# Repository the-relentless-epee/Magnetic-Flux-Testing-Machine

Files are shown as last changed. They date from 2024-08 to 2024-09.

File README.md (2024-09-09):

# Magnetic-Flux-Testing-Machine
A machine to collect data on how magnetic flux changes over distance. The end goal is to test how the air gap in an electric motor affects its performance. The machine involves spinning a disc of neodynium magnets next to a coil. The distance between the magnet disc and the coil is changed using a stepper motor, and the voltage across the coil is measured.

**Overall Assembly:**



**PCB:**





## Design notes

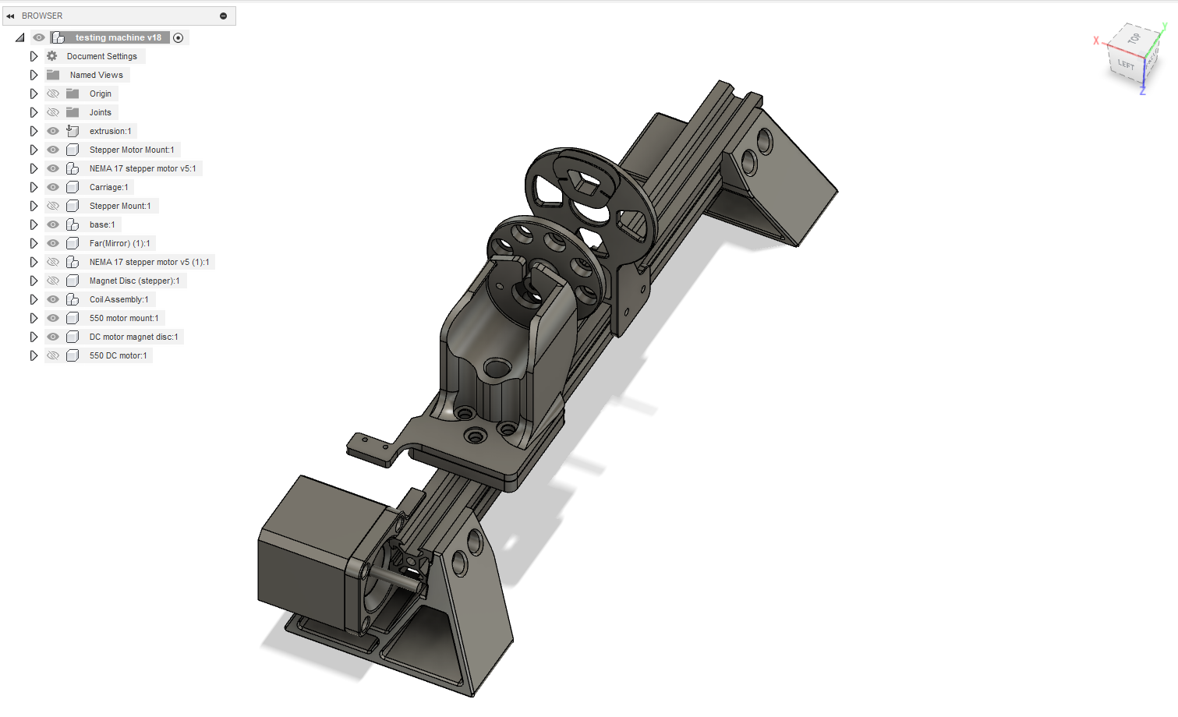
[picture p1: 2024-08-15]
CAD/Screenshot 2024-08-14 223211.png

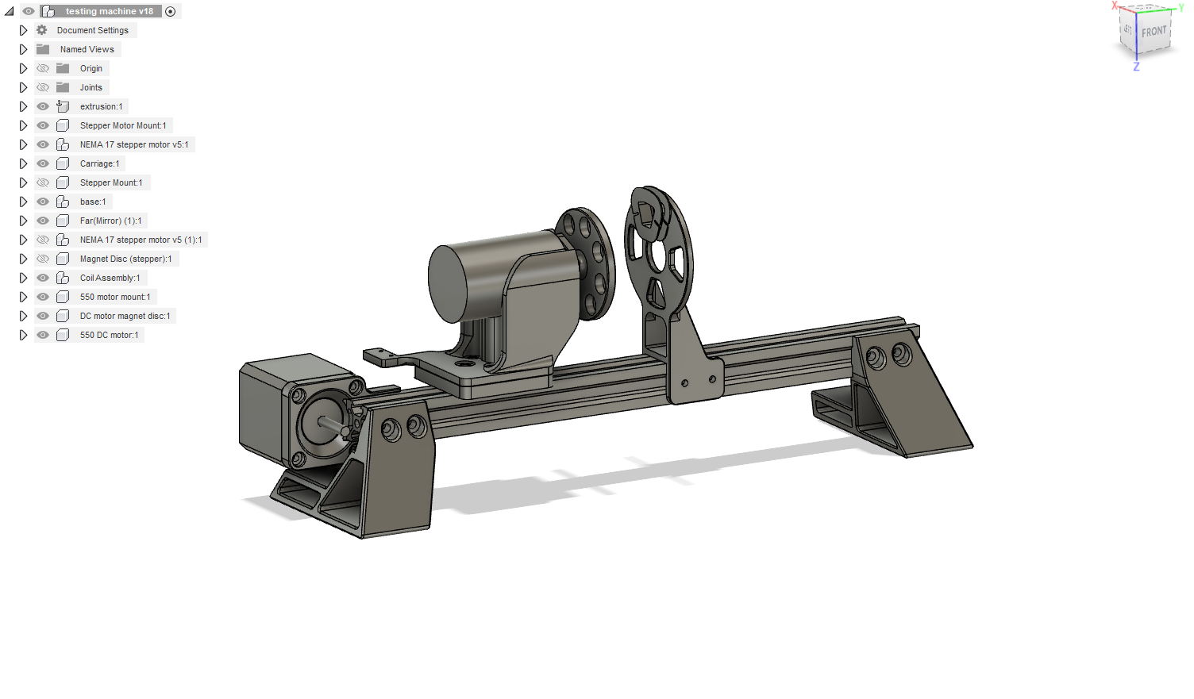
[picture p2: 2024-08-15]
CAD/Screenshot 2024-08-14 223127.png

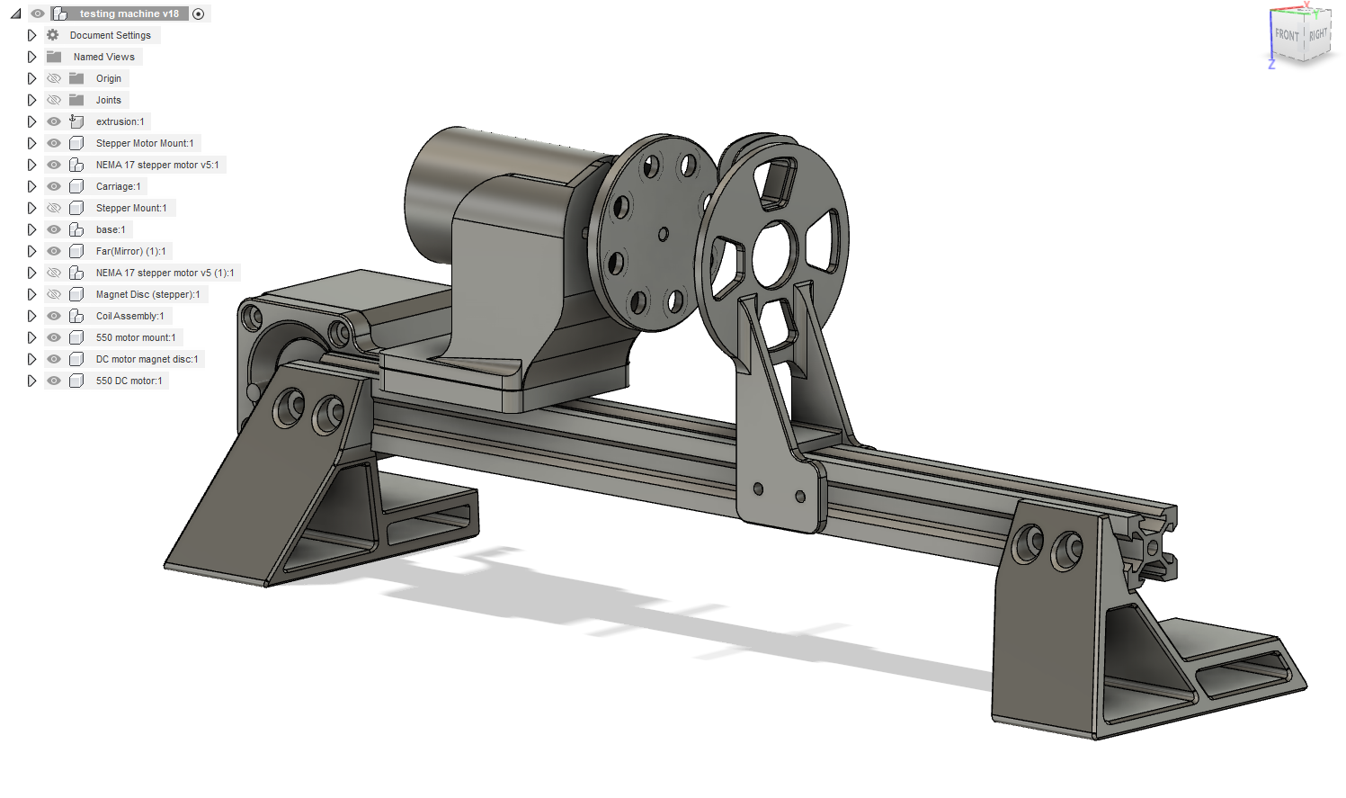
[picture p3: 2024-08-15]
CAD/Screenshot 2024-08-14 223146.png

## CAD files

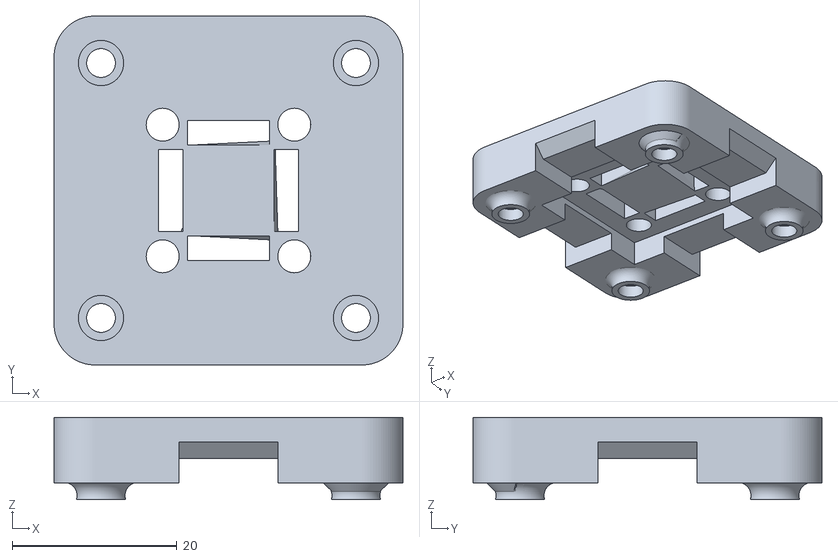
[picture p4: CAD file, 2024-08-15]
CAD/AS5600 stepper mount remix v1.stl
42.4 x 42.4 x 10.0

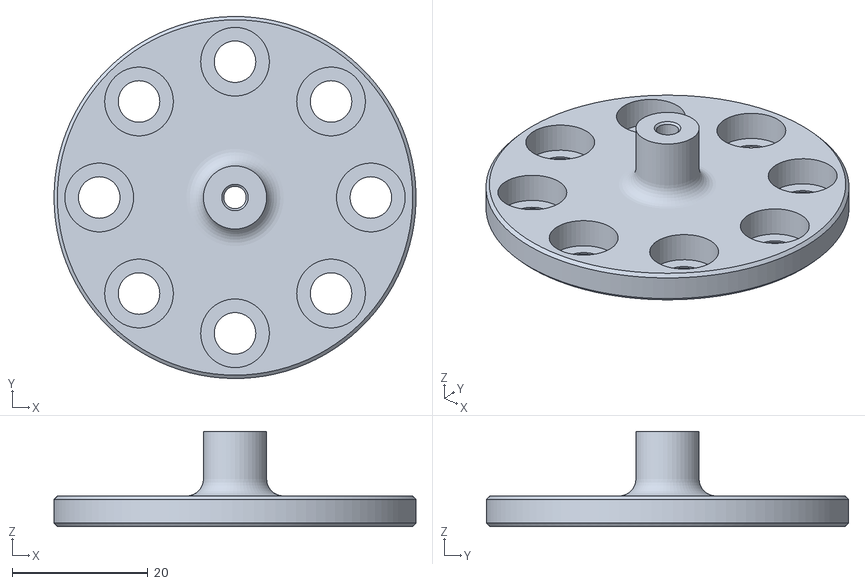
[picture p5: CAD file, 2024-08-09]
CAD/DC motor magnet disc V1.stl
53.3 x 53.3 x 14.0

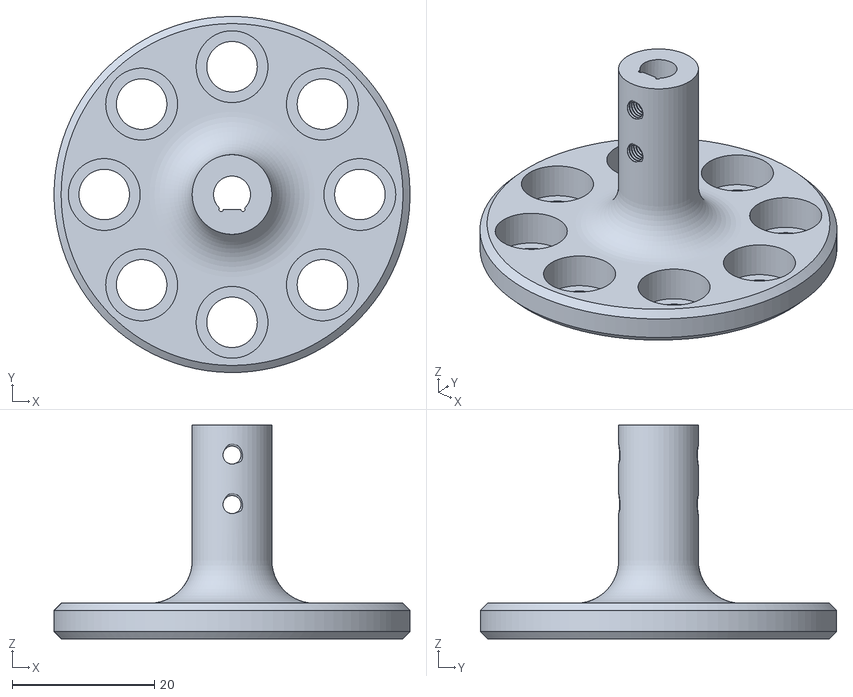
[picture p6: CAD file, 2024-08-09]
CAD/Magnet Disc V1 10x4.stl
50.0 x 50.0 x 30.0

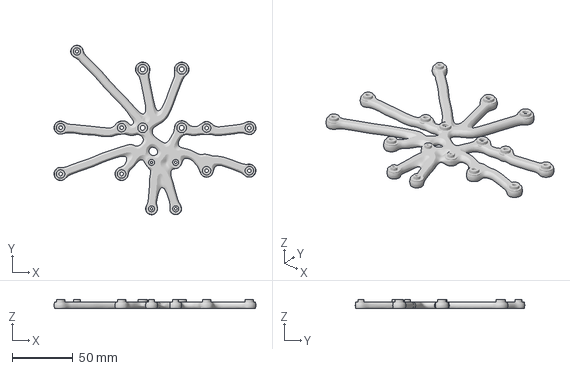
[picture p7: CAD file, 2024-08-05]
CAD/Base V1.2.3mf
165.6 x 139.0 x 7.30 mm

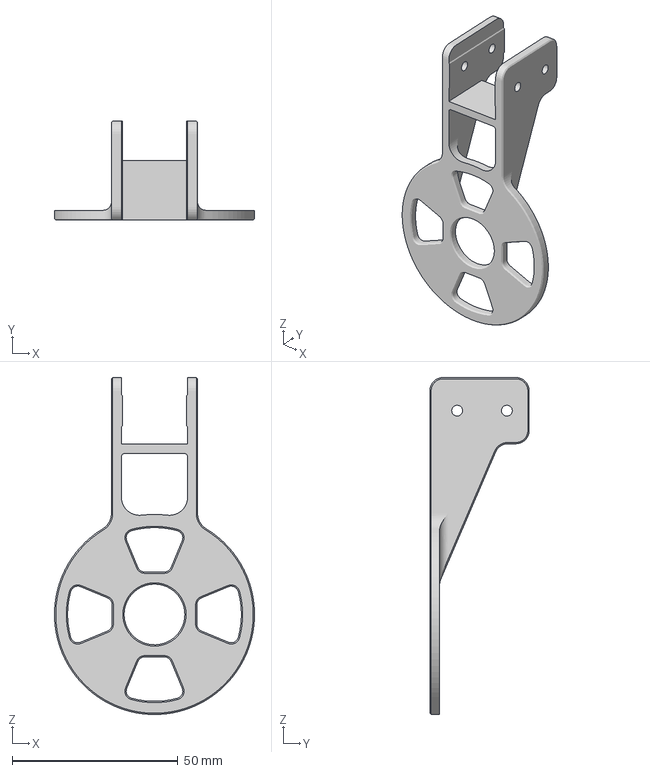
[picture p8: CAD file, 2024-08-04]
CAD/CoilBase V1.3.3mf
60.4 x 30.0 x 101.7 mm

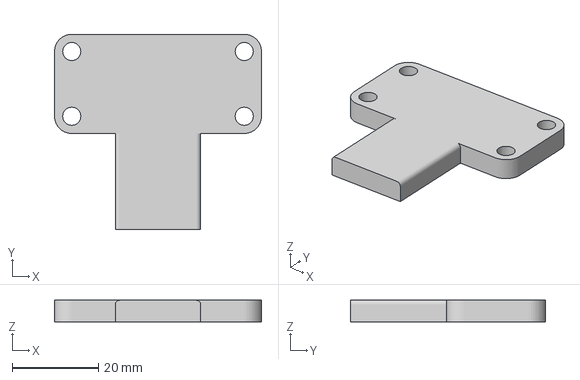
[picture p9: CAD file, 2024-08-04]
CAD/CoilBoard base adapter.3mf
48.0 x 45.3 x 5.00 mm

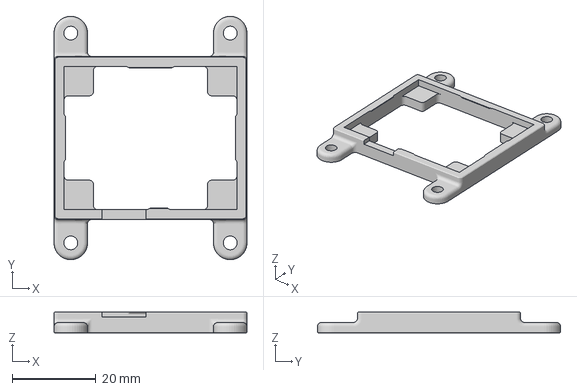
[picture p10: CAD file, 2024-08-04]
CAD/Power Board case V1.3mf
46.0 x 58.0 x 5.00 mm

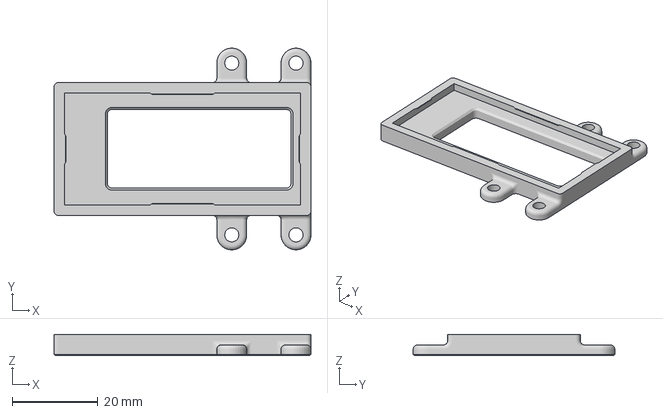
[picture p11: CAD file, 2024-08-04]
CAD/Coil board case V1.3mf
60.0 x 47.1 x 5.00 mm

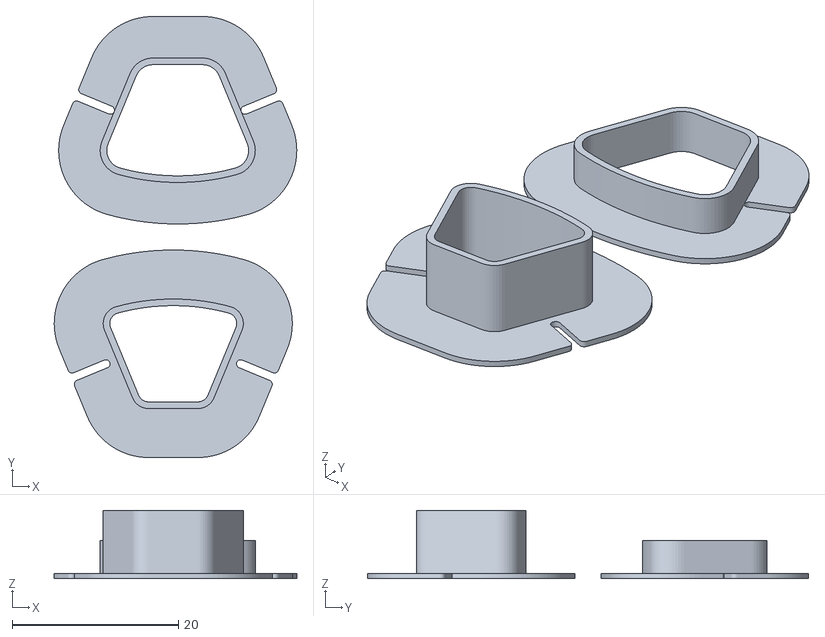
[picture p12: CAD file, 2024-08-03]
CAD/Coil V2.2.stl
29.2 x 53.1 x 8.20

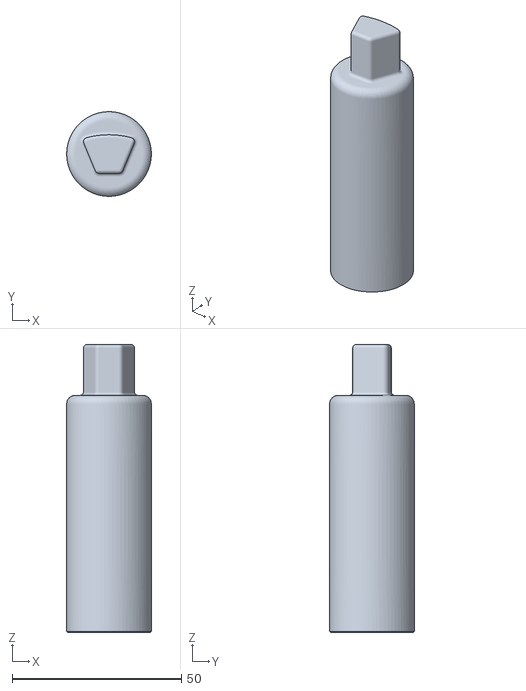
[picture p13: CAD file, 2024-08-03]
CAD/Coil winding tool.stl
25.0 x 25.0 x 85.0

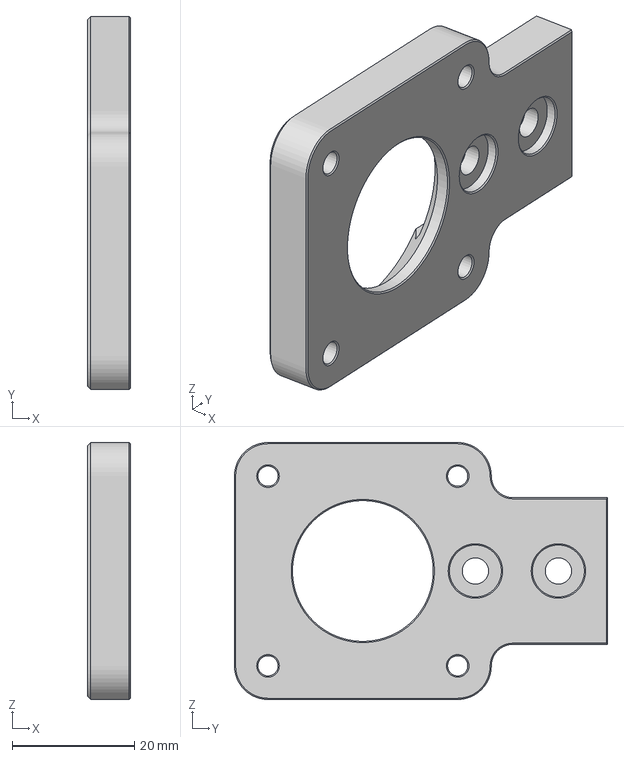
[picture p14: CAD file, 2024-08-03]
CAD/Stepper Motor Mount V1.3mf
7.00 x 61.0 x 42.0 mm

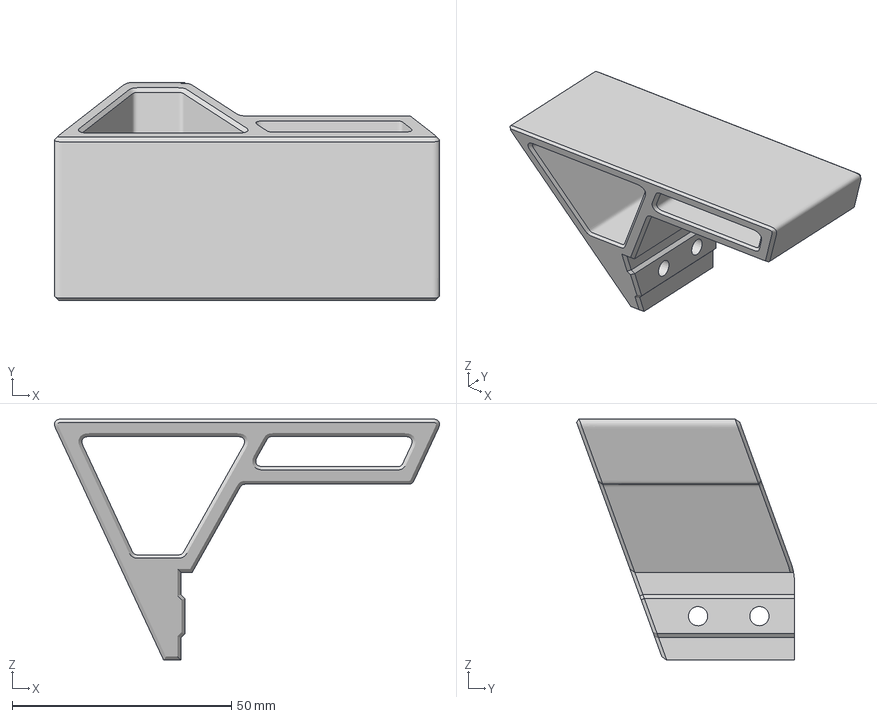
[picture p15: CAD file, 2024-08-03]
CAD/close leg V1.3mf
87.9 x 49.7 x 55.0 mm

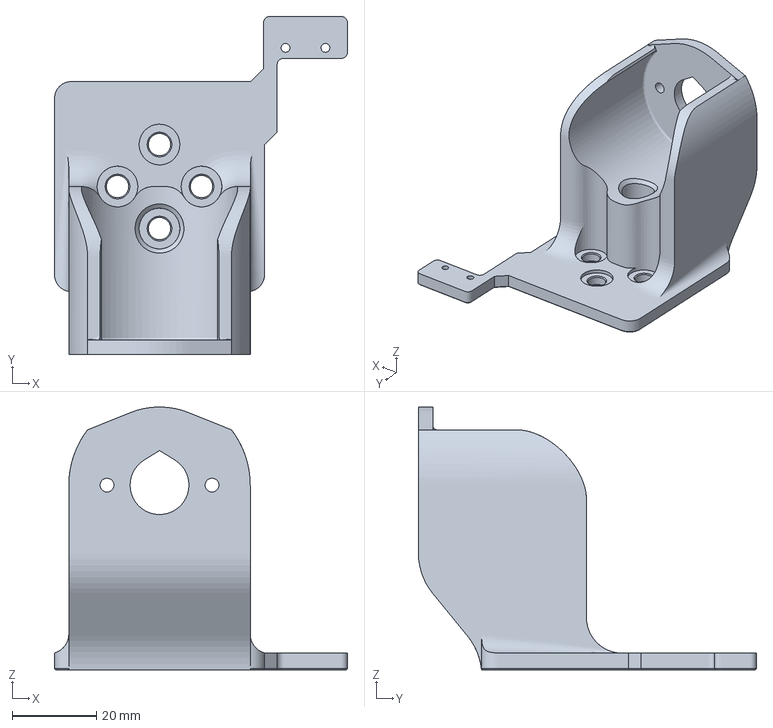
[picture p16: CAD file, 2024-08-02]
CAD/550 motor mount V1.3mf
69.8 x 80.5 x 62.6 mm

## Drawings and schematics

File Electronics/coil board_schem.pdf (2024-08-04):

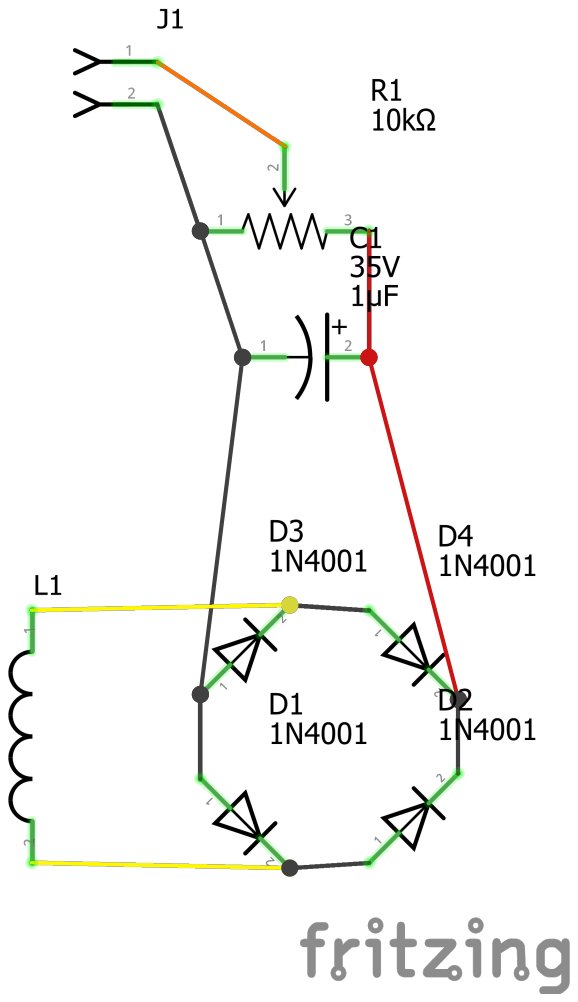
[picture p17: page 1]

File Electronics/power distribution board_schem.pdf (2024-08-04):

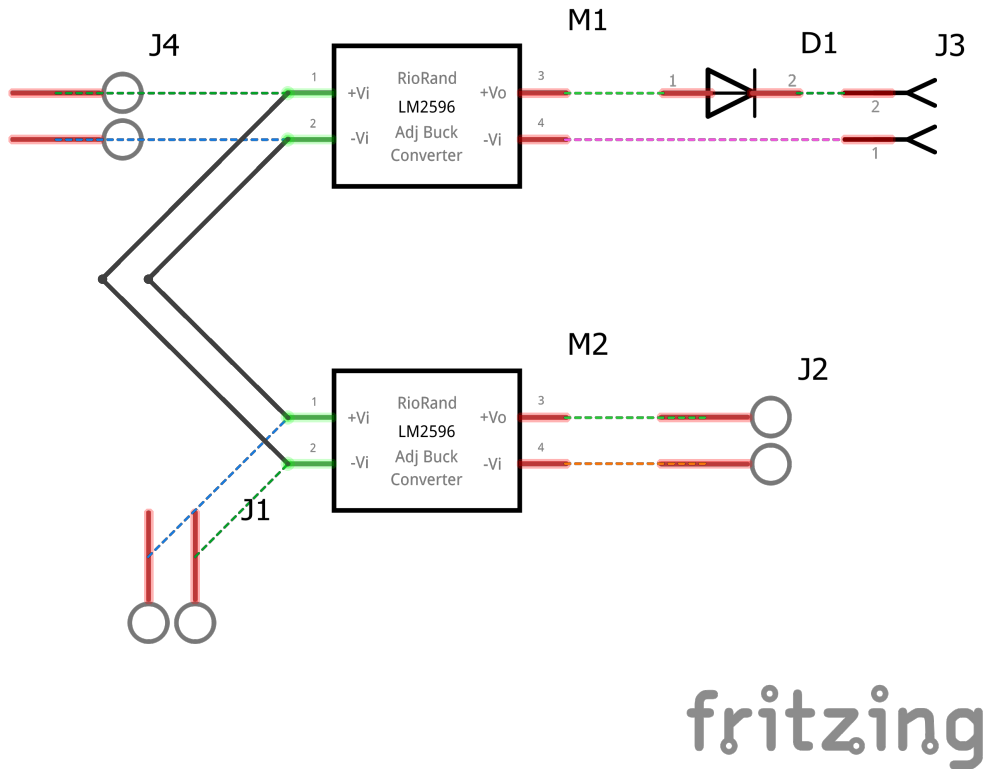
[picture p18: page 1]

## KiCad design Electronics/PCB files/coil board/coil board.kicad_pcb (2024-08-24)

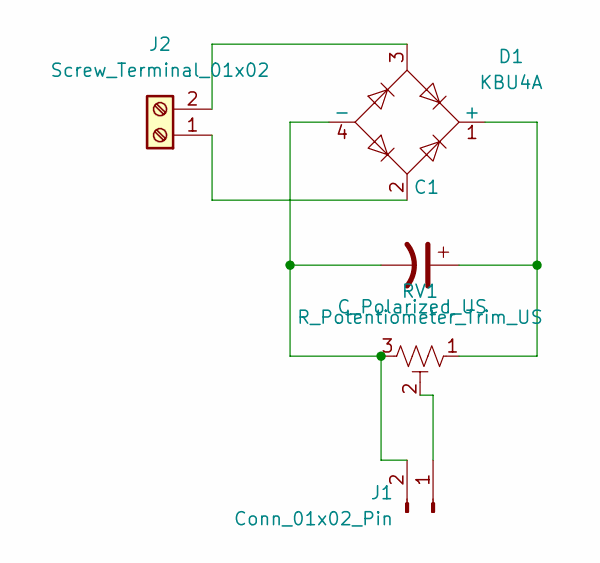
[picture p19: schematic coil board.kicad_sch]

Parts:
C1: C_Polarized_US; CP_Radial_D4.0mm_P2.00mm
D1: KBU4A; Diode_Bridge_Vishay_KBU
J1: Conn_01x02_Pin; PinHeader_1x02_P2.54mm_Vertical
J2: Screw_Terminal_01x02; TerminalBlock_RND_205-00232_1x02_P5.08mm_Horizontal
RV1: R_Potentiometer_Trim_US; Potentiometer_Vishay_T93YA_Vertical

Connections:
unnamed: C1.1, D1.1 (+), RV1.1
unnamed: C1.2, D1.4 (-), J1.2, RV1.3
unnamed: J1.1, RV1.2
unnamed: D1.2, J2.1
unnamed: D1.3, J2.2

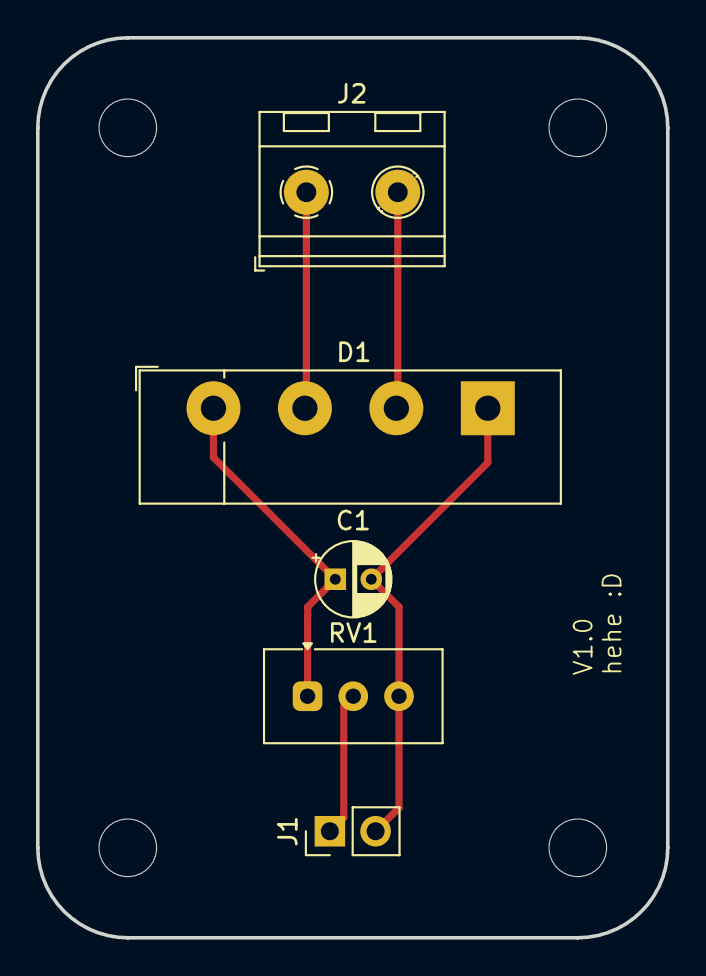
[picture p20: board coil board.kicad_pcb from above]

Board: 2 copper layers, 35.0 x 50.0 mm, 5 parts (0 on the bottom side), 5 nets.

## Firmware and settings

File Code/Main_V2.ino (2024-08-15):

//==========================libraries
#include <Arduino.h>
#include "BasicStepperDriver.h"

#include <SPI.h>
#include <SD.h>
//==========================pin definitions

# define M1 10//dc driver
# define M2 11//dc driver
# define EN 13
# define STEP 16//stepper
# define DIR 15//stepper
# define ADC 26
# define endStop 1
const int _MISO = 4;  // AKA SPI RX
const int _MOSI = 3;  // AKA SPI TX
const int _CS = 5;
const int _SCK = 2;

//==========================variables

//stepper
#define MS 4
#define MOTOR_STEPS 200
#define RPM 60
#define STEPS_PER_MM 5

BasicStepperDriver stepper(MOTOR_STEPS, DIR, STEP, EN);


//logging
#define samplesCount 10000 //samples taken per measurement cycle
#define sampleTime 5000 //sampling time in milliseconds
#define samplingInterval samplesCount/sampleTime*1000 //interval between samples in us
#define sampleDelay 1000 //delay to let voltage settle before sampling


//movement
#define moveDistance 30 //total testing distance in mm
#define stepDistance 0.1 //distance of each step in mm

#define coilDistance 60 //distance from home to coil in mm
#define initialDistance 0.2 //distance to start from coil in mm

float currentPos = 0;  //actual distance from home, in mm
int cycleCount = moveDistance/stepDistance; 
unsigned long prevMicros = 0;
unsigned long currentMicros = 0;


//==================================functions
//homing
void home(){
  Serial.println("homing");
  while (digitalRead(endStop)==1){
    stepper.move(-0.5*STEPS_PER_MM*MS); //course homing moves 0.5mm at a time
  }
  delay(100);
  stepper.move(5*STEPS_PER_MM*MS); //move back 5mm to reset the switch
  while(digitalRead(endStop)==1){ //fine homing moves one step at a time
    stepper.move(-1);
    delay(10);
  }
  Serial.println("homed");

  stepper.move(coilDistance*STEPS_PER_MM*MS);
  delay(100);
  stepper.move(-initialDistance*STEPS_PER_MM*MS);
  currentPos = coilDistance-initialDistance;
  Serial.println("homed and ready");
}
//DC motor 
void spinMotor(){
  digitalWrite(M1, 1);
  analogWrite(M2, 255); //simplified to go full speed all the time
}
void stopMotor(){
  digitalWrite(M1, 1);
  digitalWrite(M2, 1);
}
//data logging
void logData(int distance){
  File dataFile = SD.open("datalog.txt", FILE_WRITE);
  for (int i = 0; i<(samplesCount+1); i++){
    currentMicros = micros();
    while (currentMicros-prevMicros<samplingInterval){
      int data = analogRead(ADC);
      if (dataFile) {
        dataFile.print(distance);
        dataFile.print(", ");
        dataFile.println(data);
        //dataFile.close(); s
        Serial.print(distance);
        Serial.print(", ");
        Serial.println(data);
      }
      // if the file isn't open, pop up an error:
      else {
        Serial.println("error opening datalog.txt");
        break;
      }
      prevMicros = currentMicros;
    }
  }
}

//====================================================
void setup(){
  //Serial
  Serial.begin(115200);

  //SD
  Serial.println("initializing SD card");
  bool sdInitialized = false;
  SPI.setRX(_MISO);
  SPI.setTX(_MOSI);
  SPI.setSCK(_SCK);
  sdInitialized = SD.begin(_CS);
  if (!sdInitialized) {
    Serial.println("initialization failed. Things to check:");
    Serial.println("* is a card inserted?");
    Serial.println("* is your wiring correct?");
    Serial.println("* did you change the chipSelect pin to match your shield or module?");
    return;
  } else {
    Serial.println("Wiring is correct and a card is present.");
  }
  File dataFile = SD.open("datalog.txt", FILE_WRITE);

  //pin definition
  pinMode(endStop, INPUT_PULLDOWN);
  pinMode(ADC, INPUT);

  //stepper
  stepper.begin(RPM, MS);
  stepper.setEnableActiveState(LOW);
  stepper.enable(); 

  //variables
  currentPos = 0;
  delay(1000);
}

void loop(){
  home();
  File dataFile = SD.open("dataLog.txt", FILE_WRITE|O_TRUNC);
  dataFile.println("start");
  spinMotor();
  delay(1500);  
  for (int i = initialDistance; i<=moveDistance; i += stepDistance){
    delay(sampleDelay);
    logData(i);
    delay(100);
    stepper.move(-(stepDistance*STEPS_PER_MM*MS));
  }
  delay(100);
  stopMotor();
  dataFile.println("finished");
  while(true){
    stepper.disable();
  }
}

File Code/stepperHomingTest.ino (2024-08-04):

/*
 * Simple demo, should work with any driver board
 *
 * Connect STEP, DIR as indicated
 *
 * Copyright (C)2015-2017 Laurentiu Badea
 *
 * This file may be redistributed under the terms of the MIT license.
 * A copy of this license has been included with this distribution in the file LICENSE.
 */
#include <Arduino.h>
#include "BasicStepperDriver.h"

// Motor steps per revolution. Most steppers are 200 steps or 1.8 degrees/step
#define MOTOR_STEPS 200
#define RPM 60

// Since microstepping is set externally, make sure this matches the selected mode
// If it doesn't, the motor will move at a different RPM than chosen
// 1=full step, 2=half step etc.
#define MICROSTEPS 2

// All the wires needed for full functionality
#define DIR 15
#define STEP 16
#define EN 13
#define switchPin 14
//Uncomment line to use enable/disable functionality
//#define SLEEP 13

// 2-wire basic config, microstepping is hardwired on the driver
BasicStepperDriver stepper(MOTOR_STEPS, DIR, STEP, EN);

//Uncomment line to use enable/disable functionality
//BasicStepperDriver stepper(MOTOR_STEPS, DIR, STEP, SLEEP);

//step/mm = 5

int currentPos;
int coilDistance = 300*MICROSTEPS;

void home() {
  while (digitalRead(switchPin)==1){
    stepper.move(-2);
    currentPos -= 2;
    Serial.println(currentPos);
    delay(1);
  }
  delay(100);
  stepper.move(MICROSTEPS*10);
  while(digitalRead(switchPin)==1){
    stepper.move(-1);
    currentPos -= 1;
    Serial.println(currentPos);
    delay(100);
  }
  currentPos = 0;
}

void setup() {
  Serial.begin(115200);
  pinMode(switchPin, INPUT_PULLDOWN);
  stepper.begin(RPM, MICROSTEPS);
  stepper.setEnableActiveState(LOW);
  
  stepper.enable();
  stepper.move(MICROSTEPS*2);
  currentPos = 0;
    // if using enable/disable on ENABLE pin (active LOW) instead of SLEEP uncomment next line
  
}

void loop(){
  home();
  stepper.move(coilDistance);
  currentPos = coilDistance;
  Serial.println(currentPos);
  while(true){
    stepper.disable();
  }
}

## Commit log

2024-08-02 550 motor mount upload
    V1 of the "spindle" motor mount. Uses 550 DC motor, mounts onto a commonly available V-roller carriage with M5 screws. included a spot to mount a microswitch for homing.
    [550 motor mount V1.3mf]
2024-08-02 added 8x magnet rotor disc for 550 DC motor
    [DC motor magnet disc V1.2.3mf]
2024-08-03 added legs (mirror of each other)
    this is a "base" that screws onto the v-slot extrusion using M4 T-nuts. Made so that the center of gravity of the whole machine is well supported.
    [close leg V1.3mf]
2024-08-03 added stepper mount for linear movement
    uses gt2 pulley, designed to be as close to the extrusion as possible.
    [Stepper Motor Mount V1.3mf]
2024-08-03 added coil and tool for winding the wires
    uses 0.2mm enameled copper wire. ~200 turns each, 4 in total. The two halves fit over each other and should be glued.
    [Coil V2.2.stl, Coil winding tool.stl]
2024-08-03 added body to mount 4 coils to extrusion
    uses m3 bolts and t-nuts to mount to extrusion. Coils are glued to their alignment slots
    [coil body V1.3mf]
2024-08-04 initial function tests for hardware
    - tests stepper homing with microswitch
    - creating data buffers for high speed adc reading
    - logging value to an SD module
2024-08-04 added circuit design for power distribution board
    [power distribution board.fzz]
2024-08-04 organized files
    [550 motor mount V1.3mf, Coil V2.2.stl, Coil winding tool.stl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]
2024-08-04 added coil board schematics
    [coil board.fzz]
2024-08-04 added case for circuit boards
    case for power board and coil adapter board
    [Coil board case V1.3mf, CoilBoard base adapter.3mf, Power Board case V1.3mf]
2024-08-05 added base for circuit boards
    [Base V1.2.3mf]
2024-08-09 added stl files
    [DC motor magnet disc V1.stl, Magnet Disc V1 10x4.stl]
2024-08-15 added assembly images
2024-08-15 re-wrote code
    this V2 code uses standard units, all stepper movements are expressed as relationship between variables. Main function to cycle through distances is improved. Minor debugging with SD card section.
    now clears the datalog file before each testing cycle.
2024-08-15 encoder mount
    [AS5600 stepper mount remix v1.stl]
2024-08-24 added PCB design
    [Physics IA-B_Cu.gbr, Physics IA-B_Mask.gbr, Physics IA-B_Paste.gbr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]
2024-08-24 power distribution board PCB design
    [power board.kicad_sch]
